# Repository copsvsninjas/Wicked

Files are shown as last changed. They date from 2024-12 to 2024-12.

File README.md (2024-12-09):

# Wicked

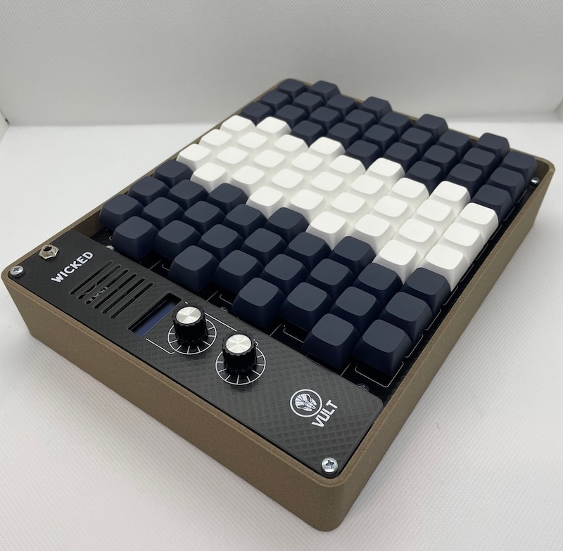
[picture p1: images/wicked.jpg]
Vult Wicked


Wicked is a MIDI controller using the [Wicki-Hayden](https://en.wikipedia.org/wiki/Wicki%E2%80%93Hayden_note_layout) layout. This project was inspired by the [Melodicade MX by KOOP Instruments](https://www.koopinstruments.com/instrument-projects/melodicade-mx).

You can read more about this project here: https://www.vult-dsp.com/post/wicked-keys

**Important**

This repository contains the first revision I made which was a quick prototype. The basic controller works fine, but some things can be improved. I have not had time to do the changes, but help is welcome if anyone wants to contribute.

## Build Notes

- The project requires two PCBs. One is used for the top layer of the switches (the mechanical switches) and the bottom contains the push switches.
- The PCBs have 1.0 mm thickness instead of the more common 1.6 mm.
- Since the PCBs are thin and big, it is necessary to use standoffs to avoid bending them when pressing keys.
- The Teensy board is placed in the bottom board.
- The mechanical switches are cut in the bottom so the plunge can be used to press the bottom switch. See the Step 7 in the build notes of the [Melodicade MX](https://www.koopinstruments.com/instrument-projects/melodicade-mx).
- It is recommended to use spacers between the top and bottom boards.
- The screws in-between the switches need to be placed before the switches are soldered otherwise they won't fit.
- Do not solder directly the Teensy board, use headers.

## Improvements that I would like to make

- The Teensy 4.1 is much more powerful than needed. It would be nice to replace it by a cheaper alternative like th RPi Pico.
- The top and bottom boards are connected using flat cable. It would be nice to have some kind of low profile connector (1 mm high) to connect the boards.
- The board was initially designed to use the Teensy 3.6 DAC. Since the 3.6 is discontinued, the PWM output of the 4.1 is used. However, it's not very good for as CV or audio output. The op-amp stages can be removed or replaced by a better CV + Gate output.
- Features like DIN MIDI output or input are not included in the PCB. I had to manually solder the wires to pins 52 and 53 of the Teensy 4.1 (see the code).
- In the prototype I made I added a battery module from Adafruit that way the controller can be used without USB power.

## License

The whole project (code and design files) are released under the Creative Commons license CC BY-NC-SA. This imposes the following restrictions:

- BY: Credit must be given to the creator.
- NC: Only noncommercial uses of the work are permitted.
- SA: Adaptations must be shared under the same terms.

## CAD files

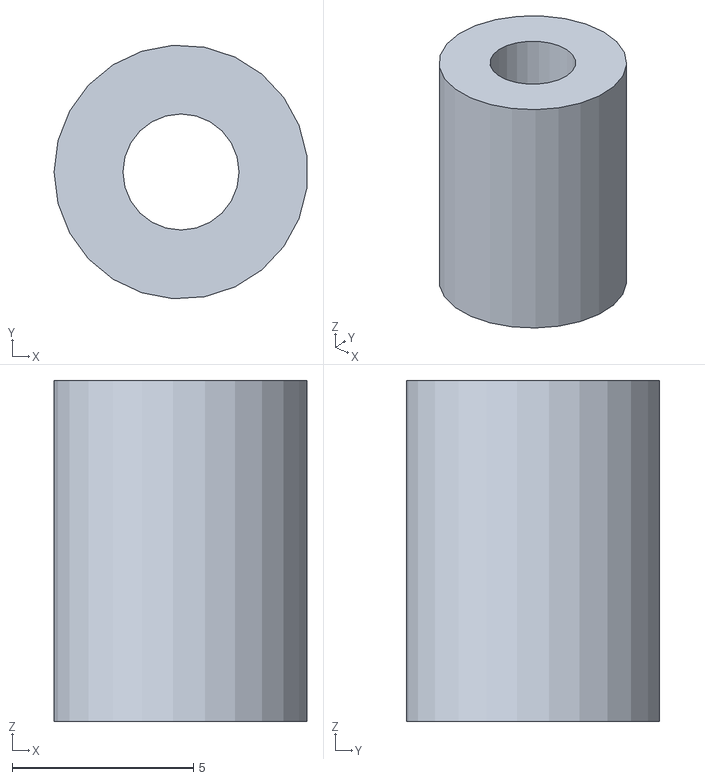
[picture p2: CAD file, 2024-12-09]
Wicked3D/WickedPanelSpacer.stl
6.97 x 6.99 x 9.40

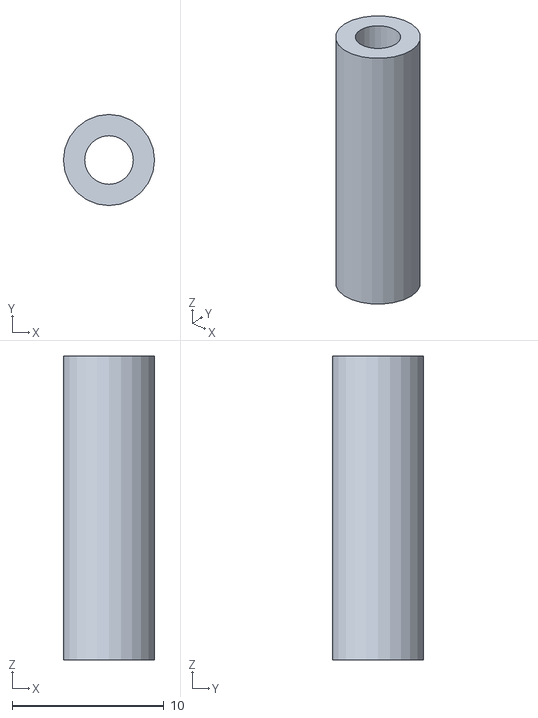
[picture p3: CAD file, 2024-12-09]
Wicked3D/WickedStandoff.stl
6.00 x 6.00 x 20.0

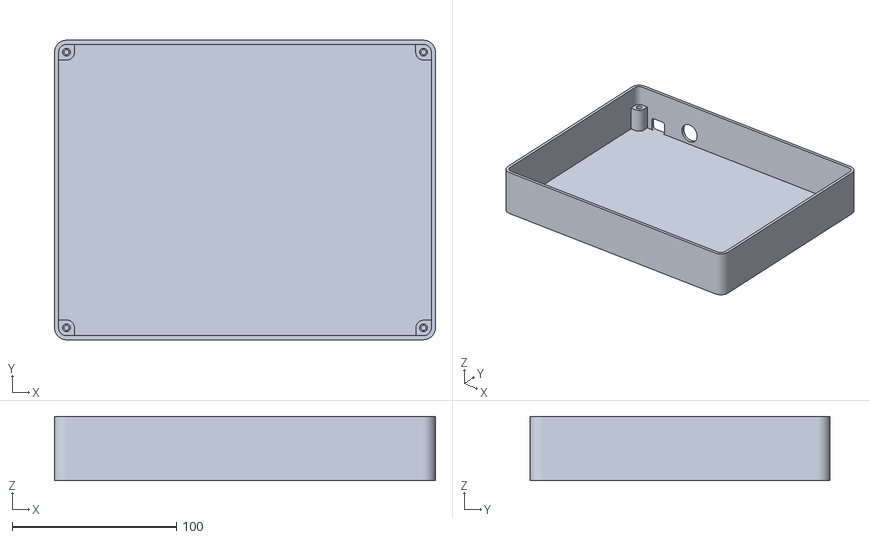
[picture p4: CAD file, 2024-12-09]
Wicked3D/WickedCase.stl
231.7 x 182.3 x 39.2

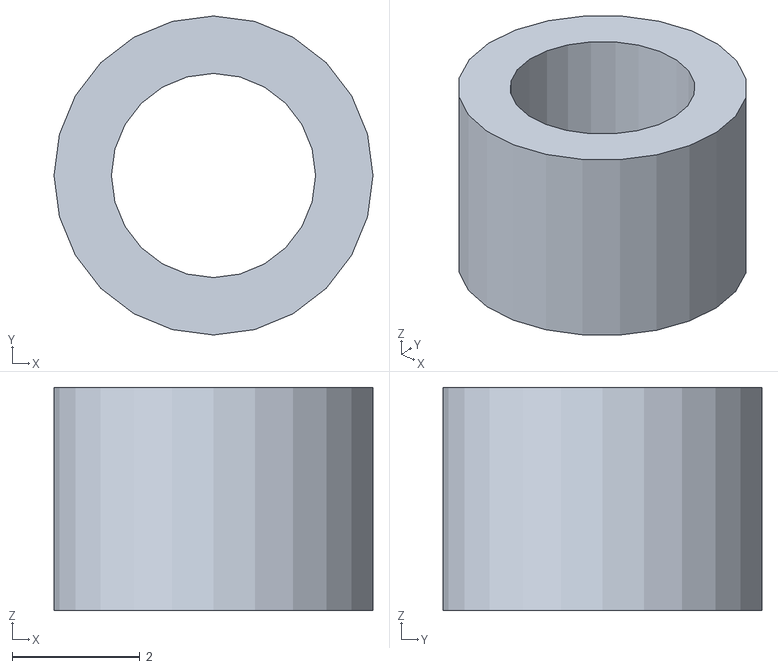
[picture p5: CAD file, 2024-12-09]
Wicked3D/WickedPCBSpacer.stl
5.00 x 5.00 x 3.50

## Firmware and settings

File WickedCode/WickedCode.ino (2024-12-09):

/*
  Author: Leonardo Laguna Ruiz (leonardo@vult-dsp.com)

  License: CC BY-NC-SA

*/

#include <stdint.h>
#include <map>
#include <MIDI.h>
#include <Adafruit_GFX.h>
#include <Adafruit_SSD1306.h>

#include "KeyScan.h"

// Serial MIDI
#ifdef ARDUINO_TEENSY36
MIDI_CREATE_INSTANCE(HardwareSerial, Serial6, MIDI);
#endif
#ifdef ARDUINO_TEENSY41
MIDI_CREATE_INSTANCE(HardwareSerial, Serial1, MIDI);
#endif

// OLED Screen
#define SCREEN_WIDTH 128    // OLED display width, in pixels
#define SCREEN_HEIGHT 32    // OLED display height, in pixels
#define OLED_RESET -1       // Reset pin # (or -1 if sharing Arduino reset pin)
#define SCREEN_ADDRESS 0x3C ///< See datasheet for Address; 0x3D for 128x64, 0x3C for 128x32
Adafruit_SSD1306 display(SCREEN_WIDTH, SCREEN_HEIGHT, &Wire, OLED_RESET);

// Keys and Encoder scanning
KeyScan key_scan;

IntervalTimer update_timer;

uint8_t decodeNote(uint8_t row, uint8_t col)
{
  switch (row)
  {
  case 8:
    return 42 + 2 * col;
  case 7:
    return 47 + 2 * col;
  case 6:
    return 54 + 2 * col;
  case 5:
    return 59 + 2 * col;
  case 4:
    return 66 + 2 * col;
  case 3:
    return 71 + 2 * col;
  case 2:
    return 78 + 2 * col;
  case 1:
    return 83 + 2 * col;
  case 0:
    return 90 + 2 * col;
  }
  return 0;
}

void UpdateKeys()
{
  key_scan.Update();
}

void setup()
{
  Serial.begin(9600);
  Serial.println("Initializing...");

  Serial.println(" - Starting MIDI");
  MIDI.begin(MIDI_CHANNEL_OMNI);

  key_scan.Setup();

#ifdef ARDUINO_TEENSY41
  Serial1.setRX(52);
  Serial1.setTX(53);
#endif

  Serial.println(" - Starting screen");
  if (!display.begin(SSD1306_SWITCHCAPVCC, SCREEN_ADDRESS))
  {
    Serial.println(F(" ! SSD1306 allocation failed"));
    for (;;)
      ; // Don't proceed, loop forever
  }

  // Start the key scanning
  update_timer.begin(UpdateKeys, 100); // tis is equivalent to scanning the keys every 1 ms

  display.clearDisplay();

  display.setTextSize(2);   // Normal 1:1 pixel scale
  display.setTextColor(1);  // Draw white text
  display.setCursor(32, 8); // Start at top-left corner
  display.cp437(true);      // Use full 256 char 'Code Page 437' font

  display.write('W');
  display.write('I');
  display.write('C');
  display.write('K');
  display.write('E');
  display.write('D');

  display.display();
  Serial.println("Done!");
}

void loop()
{
  key_scan.GetEncoder1Delta();
  key_scan.GetEncoder2Delta();
  key_scan.isButton1Pressed();
  key_scan.isButton2Pressed();

  if (key_scan.isKeyPressed())
  {
    auto key = key_scan.GetKey();
    int row = std::get<0>(key);
    int col = std::get<1>(key);
    int vel = std::get<2>(key);
    int note = decodeNote(row, col);
    if (vel != 0)
    {
      usbMIDI.sendNoteOn(note, vel, 1);
    }
    else
    {
      usbMIDI.sendNoteOff(note, vel, 1);
    }
  }

  while (usbMIDI.read())
  {
  }

  while (MIDI.read())
  {
  }
  // checkMidiInput();
}

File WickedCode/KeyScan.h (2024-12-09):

/*
  Author: Leonardo Laguna Ruiz (leonardo@vult-dsp.com)

  License: CC BY-NC-SA

*/

#include <stdint.h>
#include <map>
#include <queue>
#include <tuple>
#include <set>

#include <Bounce2.h>
#include <Encoder.h>

static const uint8_t COL_PINS[] = {9, 8, 7, 6, 5, 4, 3, 2, 1, 0};
static const uint8_t TOP_PINS[] = {15, 14, 39, 38, 37, 36, 35, 34, 33};
static const uint8_t BOT_PINS[] = {10, 11, 26, 27, 28, 29, 30, 31, 32};
static const uint16_t MAX_TICK = 0x7FFF;

static const int ENCODER1_PUSH = 17;
static const int ENCODER2_PUSH = 16;
static const int ENCODER1_PIN1 = 23;
static const int ENCODER1_PIN2 = 22;
static const int ENCODER2_PIN1 = 21;
static const int ENCODER2_PIN2 = 20;

class KeyScan
{
public:
    KeyScan()
    {
        // Initialize the grid
        for (uint8_t col = 0; col < 10; col++)
        {
            for (uint8_t row = 0; row < 9; row++)
            {
                top_grid[col][row] = -1;
                bot_grid[col][row] = -1;
            }
        }
        col = 0;
        debug_mode = false;
        tick = 0;
        encoder1_pre = 0;
        encoder2_pre = 0;
    };

    void Setup()
    {
        for (uint8_t col = 0; col < 10; col++)
            pinMode(COL_PINS[col], OUTPUT);

        for (uint8_t row = 0; row < 9; row++)
        {
            pinMode(TOP_PINS[row], INPUT_PULLDOWN);
            pinMode(BOT_PINS[row], INPUT_PULLDOWN);
        }

        encoder1_push.attach(ENCODER1_PUSH, INPUT_PULLUP);
        encoder2_push.attach(ENCODER2_PUSH, INPUT_PULLUP);
    }

    bool isKeyPressed()
    {
        return !note_queue.empty();
    }

    std::tuple<int, int, int> GetKey()
    {
        auto front = note_queue.front();
        note_queue.pop();
        return front;
    }

    bool isButton1Pressed()
    {
        encoder1_push.update();
        bool value = encoder1_push.changed() && encoder1_push.read() == LOW;
        if (debug_mode && value)
            Serial.println("Button 1 pressed");
        return value;
    }

    bool isButton2Pressed()
    {
        encoder2_push.update();
        bool value = encoder2_push.changed() && encoder2_push.read() == LOW;
        if (debug_mode && value)
            Serial.println("Button 2 pressed");
        return value;
    }

    int GetEncoder1Delta()
    {
        int delta = 0;
        int current = encoder1.read();
        if (abs(current - encoder1_pre) > 1)
        {
            delta = (encoder1_pre - current);
            encoder1.write(0);
            if (debug_mode)
            {
                Serial.print("Encoder 1 delta = ");
                Serial.println(delta);
            }
        }
        return delta;
    }

    int GetEncoder2Delta()
    {
        int delta = 0;
        int current = encoder2.read();
        if (abs(current - encoder2_pre) > 1)
        {
            delta = (encoder2_pre - current);
            encoder2.write(0);
            if (debug_mode)
            {
                Serial.print("Encoder 2 delta = ");
                Serial.println(delta);
            }
        }
        return delta;
    }

    void Update()
    {
        for (uint8_t row = 0; row < 9; row++)
        {
            bool trigger_note_on = false;
            bool trigger_note_off = false;
            int top_read = digitalRead(TOP_PINS[row]);
            int bot_read = digitalRead(BOT_PINS[row]);

            // Here we check if the button state has changed.
            // A negative number represents the OFF state
            // A positive number holds the time (tick value) at which it was pressed ON

            if (top_read && top_grid[col][row] < 0)
            { // edge up
                top_grid[col][row] = tick;
            }
            else if (!top_read && top_grid[col][row] >= 0)
            { // edge down
                top_grid[col][row] = -1;
                trigger_note_off = true;
            }

            if (bot_read && bot_grid[col][row] < 0)
            { // edge up
                bot_grid[col][row] = tick;
                trigger_note_on = true;
            }
            else if (!bot_read && bot_grid[col][row] >= 0)
            { // edge down
                bot_grid[col][row] = -1;
            }

            // Checks for faulty notes on the top layer
            if (top_grid[col][row] == -1 && trigger_note_on)
            {
                Serial.print("Failure to detect notes on the top layer. Location: ");
                Serial.print(row);
                Serial.println(col);
            }

            // If the top switch has been pressed for a while and the bottom has not been pressed
            // trigger a soft note
            if (top_grid[col][row] > 0 && bot_grid[col][row] < 0 && calculateDelta(top_grid[col][row], tick) == 127)
            {
                trigger_note_on = true;
                bot_grid[col][row] = tick;
            }

            if (trigger_note_on)
            {
                int16_t delta = calculateDelta(top_grid[col][row], bot_grid[col][row]);
                if (delta < 128)
                {
                    auto element = std::make_tuple(row, col);
                    auto search = active_notes.find(element);
                    if (search == active_notes.end())
                    {
                        int16_t velocity = 127 - delta;
                        if (velocity < 1)
                            velocity = 1;
                        if (debug_mode)
                        {
                            Serial.print("Note ON: ");
                            Serial.print(row);
                            Serial.print(" : ");
                            Serial.print(col);
                            Serial.print(" : ");
                            Serial.println(velocity);
                        }
                        active_notes.insert(element);
                        note_queue.push(std::make_tuple(row, col, velocity));
                    }
                }
            }

            if (trigger_note_off)
            {
                auto element = std::make_tuple(row, col);
                auto search = active_notes.find(element);
                if (search != active_notes.end())
                {
                    if (debug_mode)
                    {
                        Serial.print("Note OFF: ");
                        Serial.print(row);
                        Serial.print(" : ");
                        Serial.println(col);
                    }
                    active_notes.erase(element);
                    note_queue.push(std::make_tuple(row, col, 0));
                }
            }
        }
        col = (col + 1) % 10;
        if (col == 0)
        {
            // reset the tick
            tick = (tick + 1) % MAX_TICK;
        }
        // We select the next column in order to give it time to stabilize
        selectColumn(col);
    }

    void DebugMode(bool active)
    {
        debug_mode = active;
    }
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

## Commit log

2024-12-09 Adds Rev 1.0 files.
    [WickedBoard.kicad_sch]
2024-12-09 Adds the STL files for 3D printing.
    [WickedCase.stl, WickedPCBSpacer.stl, WickedPanelSpacer.stl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]
